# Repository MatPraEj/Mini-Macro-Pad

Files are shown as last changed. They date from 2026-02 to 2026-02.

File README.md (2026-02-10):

# Mini-Macro-Pad

Mini macropad is a 6 key "macropad" with a rotary encoder and OLED Display to allow for flexibility and the very important cool factor :D.

Why macropad in ""? Although it can function as a macropad when used with VIA, its main purpose is to act as a second mini keyboard with the RCTL, RSFT, LEFT, UP, DOWN, RIGHT buttons to serve as a sort of controller for PC where the second player plays on arrow keys and two buttons!

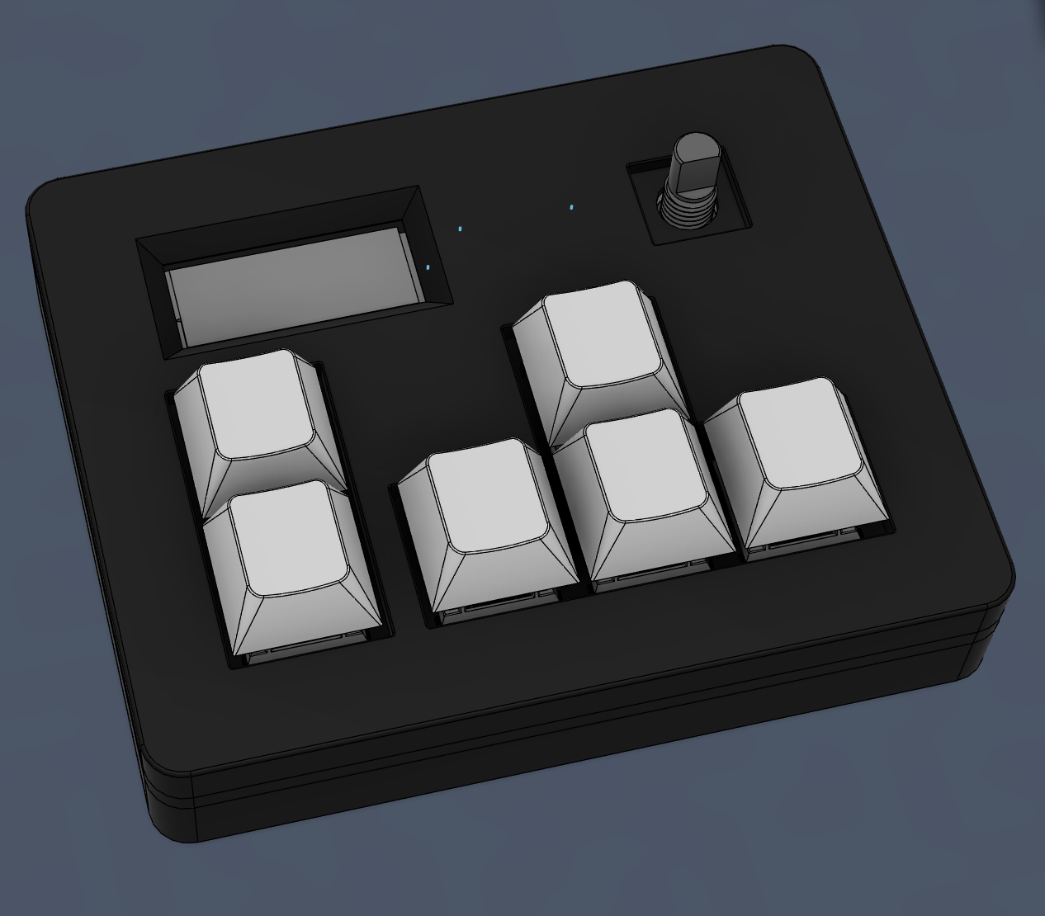
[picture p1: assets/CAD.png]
the whole macropad assembly


## Features:
- a Sturdy case with multiple points where the PCB is supported to minimize flex
- a recessed USB-C port
- an EC11 Rotary encoder for versatilty
- a 32x128 OLED display for cool factor
- 6 keys
- and [VIA](https://www.caniusevia.com/) support

## CAD Model
The Mini macropad is put together using 4 M3x16mm bolts and 4 heatset inserts, with another 1 M3x6 bolt holding the PCB (there are slots for 3 if it turns out 1 is unstable)

There are 3 seperate pieces of the case: the bottom where the PCB sits on a raised ledge around the edges as well as center supports; the middle part that acts as the plate for keyswitches, it is 3mm thick to allow for sturdiness but has a recess around the switch holes so they can clip in; and the top which covers the middle plate and sits flush with the bottom of the keycaps.

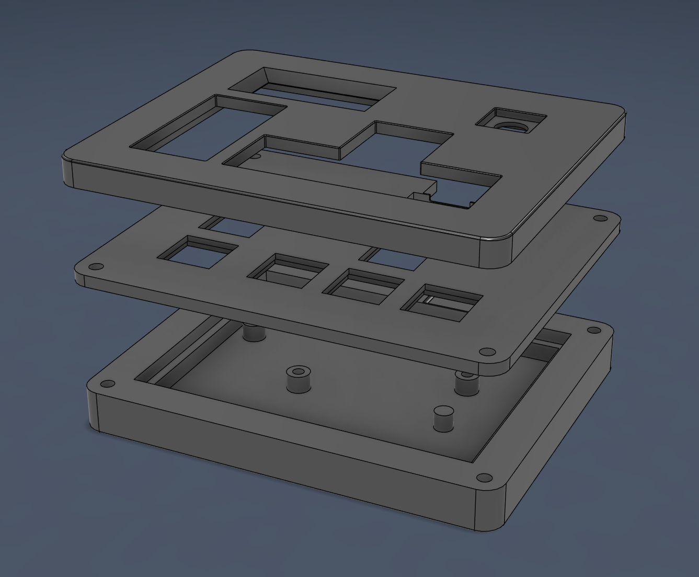
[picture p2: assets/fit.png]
how the case parts align


Learning Fusion 360 was a bit of a pain but I got the hang of it, now I can describe my experience only with one word: Nifty.

## PCB
Below is my PCB made in KiCad, Joe Scotto's guide's came in incredibly handy with this one.

I also snuck in a silkscreen easter egg of a sketch of the mini macropad :D

Schematic:

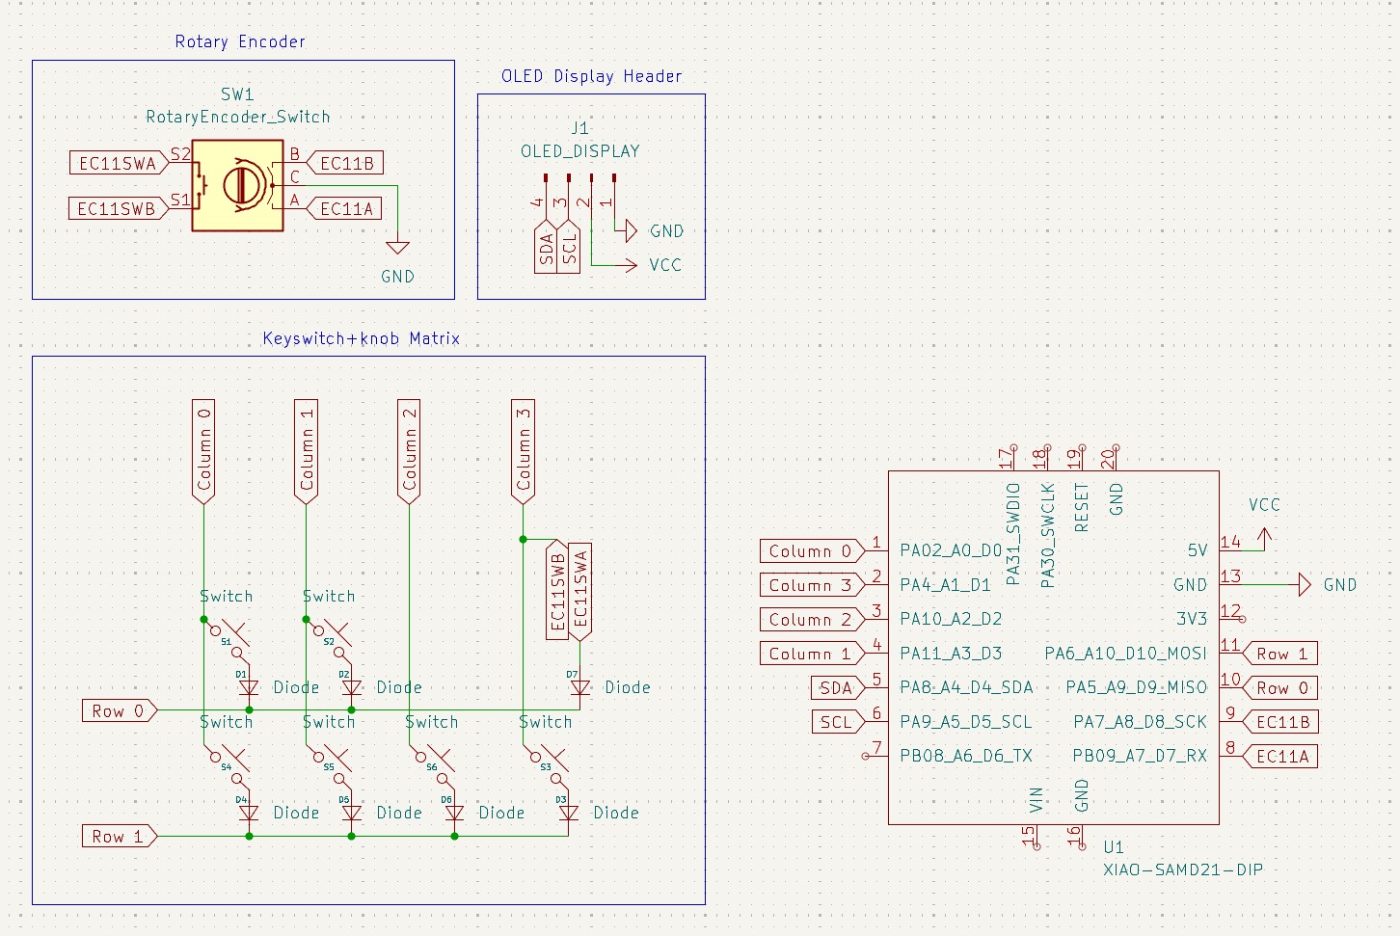
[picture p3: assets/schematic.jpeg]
the PCB schematic


PCB:

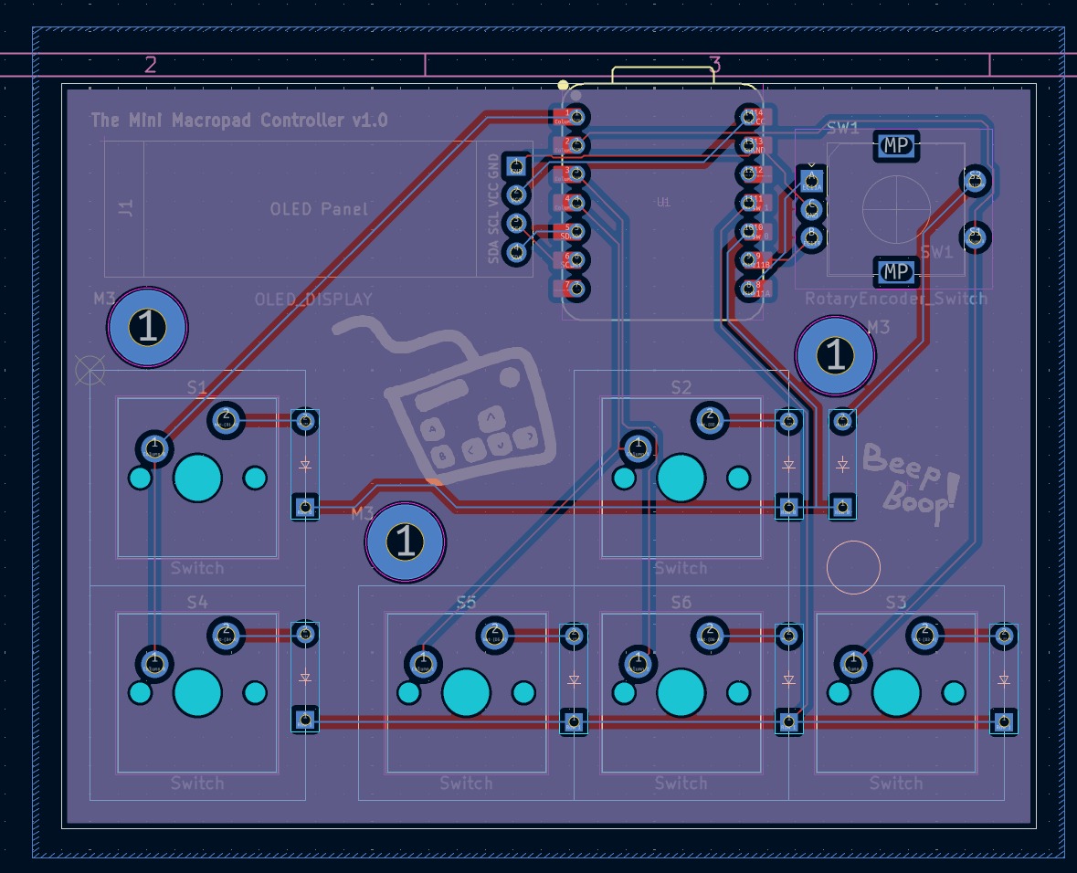
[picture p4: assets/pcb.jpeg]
the PCB


## Firmware
I used [QMK](https://qmk.fm/) for the firmware here, it was a massive pain to setup but if VIA works (fingers crossed!) it will be worth it, if it doesn't I'll do whatever to make it work.

By default:
- the rotary encoder changes volume and mutes/unmutes media when pressed
- the 6 keys act as a mini gamepad posing as UP, DOWN, LEFT, RIGHT and RCTL and RSFT
- the OLED screen displays an animation of a seal (by request of a friend)

VIA will allow me to change these keyboard mappings, allowing flexibility and allowing me to use it as an actual macropad :D

## BOM
Below is everything I'll need to build this:
- 6x Cherry MX Switches
- 6x DSA Keycaps
- 4x M3x5x4 Heatset inserts
- 4x M3x16 SHCS Bolts
- 1x M3x6 SHCS Bolt (I will source this myself)
- 7x DO-35 Diodes
- 1x 0.91" 128x32 OLED Display
- 1x EC11 Rotary Encoder
- 1x Seed Studio XIAO RP2040
- 2x 2.54mm 1x7 pin headers
- 1x 2.54mm 1x4 pin header
- 1x Case (3 3d printed parts)
- 1x Custom PCB

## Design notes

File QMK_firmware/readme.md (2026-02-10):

# mini_macropad

mini_macropad

*A short description of the keyboard/project*

* Keyboard Maintainer: [Matej Prazsky](https://github.com/MatPraEj)
* Hardware Supported: *The PCBs, controllers supported*
* Hardware Availability: *Links to where you can find this hardware*

Make example for this keyboard (after setting up your build environment):

    make mini_macropad:default

Flashing example for this keyboard:

    make mini_macropad:default:flash

See the [build environment setup](https://docs.qmk.fm/#/getting_started_build_tools) and the [make instructions](https://docs.qmk.fm/#/getting_started_make_guide) for more information. Brand new to QMK? Start with our [Complete Newbs Guide](https://docs.qmk.fm/#/newbs).

## Bootloader

Enter the bootloader in 3 ways:

* **Bootmagic reset**: Hold down the key at (0,0) in the matrix (usually the top left key or Escape) and plug in the keyboard
* **Physical reset button**: Briefly press the button on the back of the PCB - some may have pads you must short instead
* **Keycode in layout**: Press the key mapped to `QK_BOOT` if it is available

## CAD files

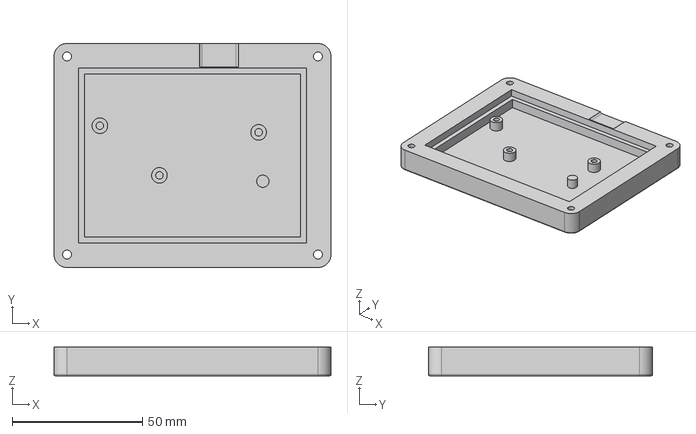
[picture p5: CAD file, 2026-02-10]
production/Bottom.step
106.4 x 86.0 x 11.0 mm

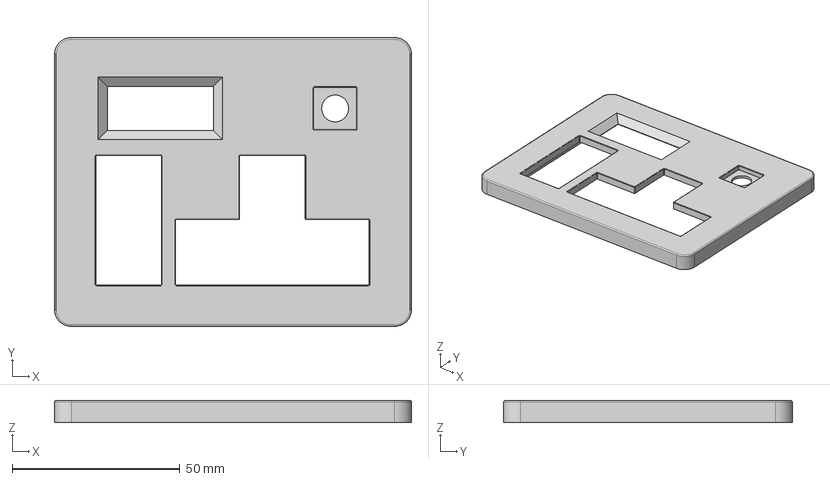
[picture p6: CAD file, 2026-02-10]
production/Top.step
106.4 x 86.0 x 6.60 mm

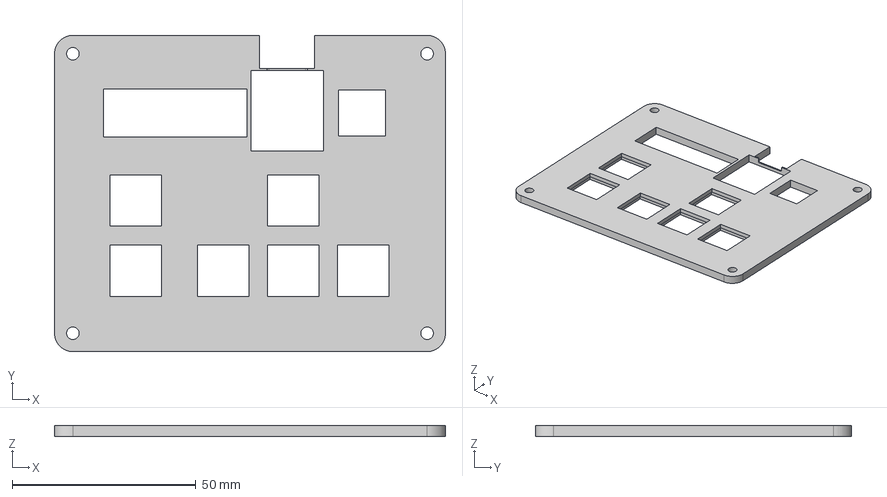
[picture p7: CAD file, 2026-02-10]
production/Middle.step
106.4 x 86.0 x 3.00 mm

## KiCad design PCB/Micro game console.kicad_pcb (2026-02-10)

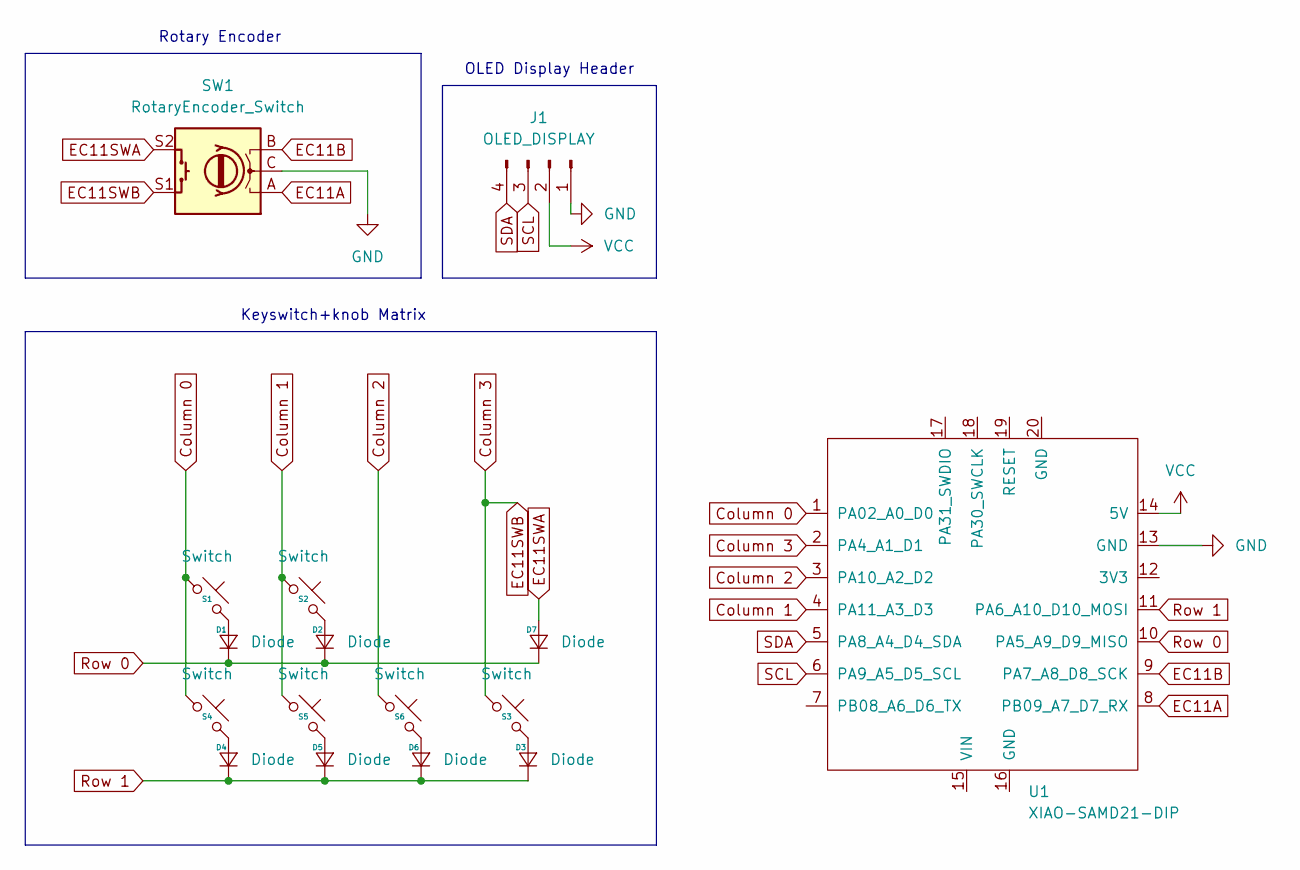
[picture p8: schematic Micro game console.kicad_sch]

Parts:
D1, D2, D3, D4, D5, D6, D7: Diode; Diode_DO-35
J1: OLED_DISPLAY; SSD1306-0.91-OLED-4pin-128x32
S1, S2, S3, S4, S5, S6: Switch; MX_PCB_1.00u
SW1: RotaryEncoder_Switch; RotaryEncoder_Alps_EC11E-Switch_Vertical_H20mm
U1: XIAO-SAMD21-DIP

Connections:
Column 0: S1.1, S4.1, U1.1 (PA02_A0_D0)
Column 1: S2.1, S5.1, U1.4 (PA11_A3_D3)
Column 2: S6.1, U1.3 (PA10_A2_D2)
Column 3: S3.1, SW1.S1, U1.2 (PA4_A1_D1)
EC11A: SW1.A, U1.8 (PB09_A7_D7_RX)
EC11B: SW1.B, U1.9 (PA7_A8_D8_SCK)
EC11SWA: D7.2 (A), SW1.S2
GND: J1.1, SW1.C, U1.13 (GND)
unnamed: D1.2 (A), S1.2
unnamed: D2.2 (A), S2.2
unnamed: D3.2 (A), S3.2
unnamed: D4.2 (A), S4.2
unnamed: D5.2 (A), S5.2
unnamed: D6.2 (A), S6.2
Row 0: D1.1 (K), D2.1 (K), D7.1 (K), U1.10 (PA5_A9_D9_MISO)
Row 1: D3.1 (K), D4.1 (K), D5.1 (K), D6.1 (K), U1.11 (PA6_A10_D10_MOSI)
SCL: J1.3, U1.6 (PA9_A5_D5_SCL)
SDA: J1.4, U1.5 (PA8_A4_D4_SDA)
VCC: J1.2, U1.14 (5V)

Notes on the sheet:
OLED Display Header
Rotary Encoder
Keyswitch+knob Matrix

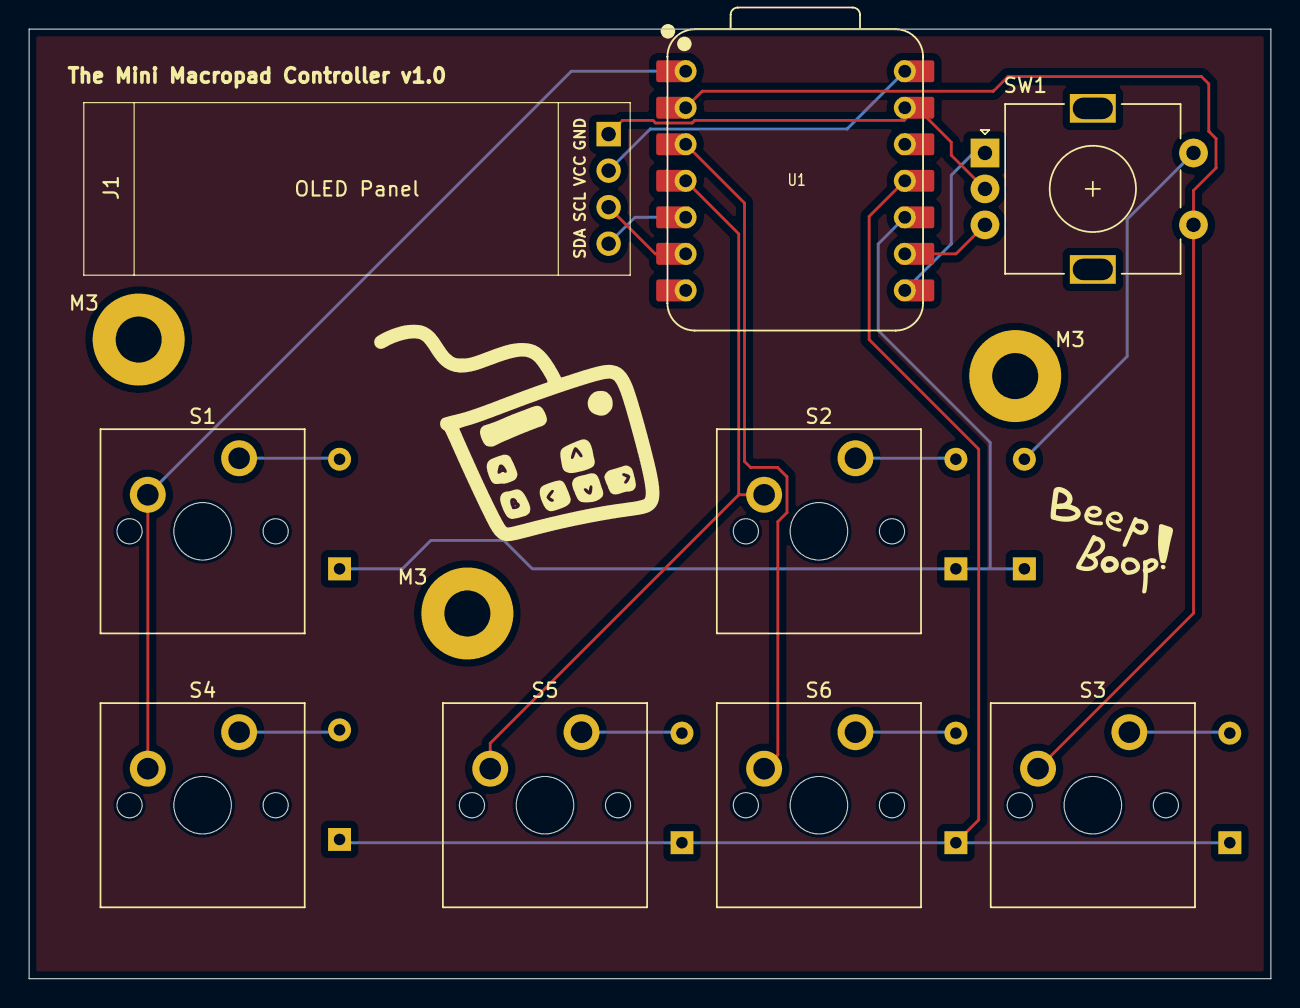
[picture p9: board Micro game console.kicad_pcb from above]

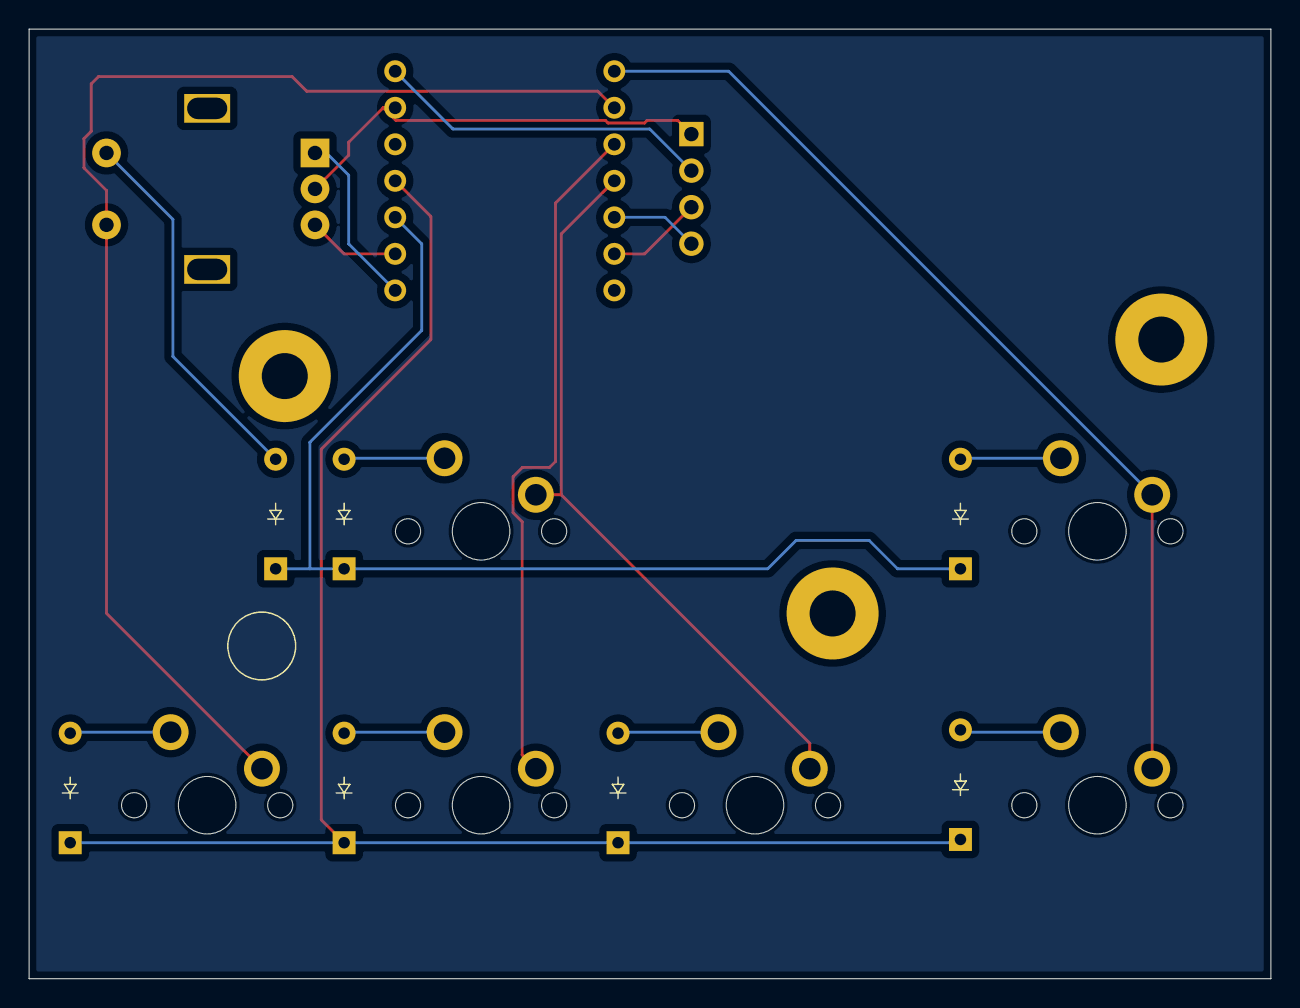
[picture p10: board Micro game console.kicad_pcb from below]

Board: 2 copper layers, 86.4 x 66.0 mm, 20 parts (7 on the bottom side), 19 nets.

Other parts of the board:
M3, M3#2, M3#3: MountingHole_3.2mm_M3_Pad
sdasd: LOGO; beep_boop

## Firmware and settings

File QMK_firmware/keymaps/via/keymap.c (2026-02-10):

// Copyright 2023 QMK
// SPDX-License-Identifier: GPL-2.0-or-later

#include QMK_KEYBOARD_H

const uint16_t PROGMEM keymaps[][MATRIX_ROWS][MATRIX_COLS] = {
    [0] = LAYOUT(
        KC_RSFT,   KC_UP,   KC_MUTE,
        KC_RCTL,   KC_LEFT,   KC_DOWN,   KC_RIGHT
    )
};

#if defined (ENCODER_MAP_ENABLE)
const uint16_t PROGMEM encoder_map[][NUM_ENCODERS][2] = {
    [0] = { ENCODER_CCW_CW(KC_VOLD, KC_VOLU) } //set functions of rotating encoder
}; 
#endif

#if defined (OLED_ENABLE)

// Animation parameters
#define FRAME_DURATION 333 // how long each frame is in ms

// Animation variables
uint32_t timer = 0;
uint8_t current_frame = 0;

// Render animation
static void render_animation(void) {

    // 'frame_0_delay-0', 128x32px
    static const char epd_bitmap_frame_0_delay_0 [] PROGMEM = {
        0x00, 0x00, 0x00, 0x00, 0x00, 0x00, 0x00, 0x00, 0x00, 0x00, 0x00, 0x00, 0x00, 0x00, 0x00, 0x00, 
        0x00, 0x00, 0x00, 0x00, 0xf0, 0x00, 0x00, 0x00, 0x00, 0x00, 0x00, 0x7f, 0xf8, 0x00, 0x00, 0x00, 
        0x00, 0x00, 0x00, 0x01, 0x98, 0x00, 0x00, 0x00, 0x00, 0x00, 0x07, 0xc0, 0x0e, 0x00, 0x00, 0x00, 
        0x00, 0x00, 0x00, 0x01, 0x0c, 0x00, 0x00, 0x00, 0x00, 0x00, 0x3c, 0x00, 0x01, 0x80, 0x00, 0x00, 
        0x00, 0x00, 0x00, 0x03, 0x04, 0x00, 0x00, 0x00, 0x00, 0x03, 0xe0, 0x00, 0x00, 0xc0, 0x00, 0x00, 
        0x00, 0x00, 0x00, 0x02, 0x06, 0x00, 0x00, 0x00, 0x00, 0x1e, 0x00, 0x00, 0x06, 0x20, 0x00, 0x00, 
        0x00, 0x00, 0x00, 0x02, 0x02, 0x00, 0x00, 0x00, 0x00, 0xf0, 0x00, 0x00, 0x04, 0x30, 0x00, 0x00, 
        0x00, 0x00, 0x00, 0x02, 0x02, 0x00, 0x00, 0x00, 0x03, 0x80, 0x00, 0x00, 0x00, 0x10, 0x00, 0x00, 
        0x00, 0x00, 0x00, 0x02, 0x02, 0x00, 0x00, 0x00, 0x0e, 0x00, 0x00, 0x00, 0x00, 0x08, 0x00, 0x00, 
        0x00, 0x00, 0x00, 0x02, 0x02, 0x00, 0x00, 0x00, 0x18, 0x00, 0x00, 0x00, 0x00, 0x04, 0x00, 0x00, 
        0x00, 0x00, 0x00, 0x01, 0x02, 0x00, 0x00, 0x00, 0x70, 0x00, 0x00, 0x00, 0x00, 0x84, 0x00, 0x00, 
        0x00, 0x00, 0x00, 0x01, 0x02, 0x00, 0x00, 0x01, 0xc0, 0x00, 0x00, 0x00, 0x00, 0x64, 0x00, 0x00, 
        0x00, 0x00, 0x03, 0xff, 0x82, 0x00, 0x00, 0x0f, 0x00, 0x00, 0x00, 0x00, 0x00, 0x18, 0x00, 0x00, 
        0x00, 0x00, 0x0e, 0x01, 0x87, 0x80, 0x00, 0x78, 0x00, 0x00, 0x00, 0x00, 0x00, 0xf0, 0x00, 0x00, 
        0x00, 0x00, 0x18, 0x00, 0xcc, 0xf0, 0x03, 0x80, 0x00, 0x00, 0x00, 0x00, 0x07, 0x80, 0x00, 0x00, 
        0x00, 0x00, 0x10, 0x00, 0x58, 0x0f, 0xfe, 0x00, 0x00, 0x00, 0x00, 0x00, 0x7c, 0x00, 0x00, 0x00, 
        0x00, 0x00, 0x18, 0x00, 0x70, 0x00, 0x00, 0x00, 0x00, 0x00, 0x00, 0x40, 0xc0, 0x00, 0x00, 0x00, 
        0x00, 0x00, 0x0e, 0x00, 0xc0, 0x00, 0x00, 0x00, 0x00, 0x00, 0x00, 0x41, 0x80, 0x00, 0x00, 0x00, 
        0x00, 0x00, 0x03, 0x81, 0x80, 0x00, 0x00, 0x00, 0x00, 0x00, 0x00, 0x23, 0x00, 0x00, 0x00, 0x00, 
        0x00, 0x00, 0x00, 0xff, 0x80, 0x00, 0x00, 0x00, 0x00, 0x00, 0x08, 0x1e, 0x00, 0x00, 0x00, 0x00, 
        0x00, 0x00, 0x00, 0x00, 0x80, 0x00, 0x00, 0x00, 0x00, 0x00, 0x08, 0x08, 0x00, 0x00, 0x00, 0x00, 
        0x00, 0x00, 0x00, 0x00, 0x40, 0x00, 0x00, 0x00, 0x00, 0x00, 0x04, 0x04, 0x00, 0x00, 0x00, 0x00, 
        0x00, 0x00, 0x00, 0x00, 0x20, 0x00, 0x00, 0x00, 0x00, 0x00, 0x04, 0x03, 0x00, 0x00, 0x00, 0x00, 
        0x00, 0x00, 0x00, 0x00, 0x30, 0x00, 0x00, 0x00, 0x00, 0x00, 0x02, 0x00, 0x80, 0x00, 0x00, 0x00, 
        0x00, 0x00, 0x00, 0x00, 0x18, 0x00, 0x00, 0x00, 0x00, 0x00, 0x06, 0x00, 0xc0, 0x00, 0x00, 0x00, 
        0x00, 0x00, 0x00, 0x00, 0x06, 0x00, 0x00, 0x00, 0x00, 0xff, 0xfd, 0x00, 0x30, 0x00, 0x00, 0x00, 
        0x00, 0x00, 0x00, 0x00, 0x03, 0x80, 0x00, 0x00, 0x1f, 0x80, 0x00, 0x80, 0x0c, 0x00, 0x00, 0x00, 
        0x00, 0x00, 0x00, 0x00, 0x00, 0xe0, 0x00, 0x00, 0x70, 0x00, 0x00, 0x40, 0x03, 0x00, 0x00, 0x00, 
        0x00, 0x00, 0x00, 0x00, 0x00, 0x3e, 0x00, 0x01, 0xc0, 0x00, 0x00, 0x20, 0x01, 0x00, 0x00, 0x00, 
        0x00, 0x00, 0x00, 0x00, 0x00, 0x01, 0xfc, 0x0f, 0x00, 0x00, 0x00, 0x18, 0x03, 0x00, 0x00, 0x00, 
        0x00, 0x00, 0x00, 0x00, 0x00, 0x00, 0x07, 0xf8, 0x00, 0x00, 0x00, 0x07, 0xfc, 0x00, 0x00, 0x00, 
        0x00, 0x00, 0x00, 0x00, 0x00, 0x00, 0x00, 0x00, 0x00, 0x00, 0x00, 0x00, 0x00, 0x00, 0x00, 0x00
    };
    // 'frame_1_delay-0', 128x32px
    static const char epd_bitmap_frame_1_delay_0 [] PROGMEM = {
        0x00, 0x00, 0x00, 0x00, 0x00, 0x00, 0x00, 0x00, 0x00, 0x00, 0x00, 0x00, 0x00, 0x00, 0x00, 0x00, 
        0x00, 0x00, 0x00, 0x00, 0x00, 0x00, 0x00, 0x00, 0x00, 0x00, 0x00, 0xff, 0x80, 0x00, 0x00, 0x00, 
        0x00, 0x00, 0x00, 0x00, 0x00, 0x00, 0x00, 0x00, 0x00, 0x00, 0x07, 0x80, 0xf0, 0x00, 0x00, 0x00, 
        0x00, 0x00, 0x00, 0x00, 0x00, 0x00, 0x00, 0x00, 0x00, 0x00, 0x38, 0x00, 0x1c, 0x00, 0x00, 0x00, 
        0x00, 0x00, 0x00, 0x1f, 0x80, 0x00, 0x00, 0x00, 0x00, 0x00, 0xe0, 0x00, 0x46, 0x00, 0x00, 0x00, 
        0x00, 0x00, 0x00, 0x30, 0xc0, 0x00, 0x00, 0x00, 0x00, 0x03, 0x80, 0x00, 0x62, 0x00, 0x00, 0x00, 
        0x00, 0x00, 0x00, 0x20, 0x60, 0x00, 0x00, 0x00, 0x00, 0x0e, 0x00, 0x00, 0x01, 0x00, 0x00, 0x00, 
        0x00, 0x00, 0x00, 0x30, 0x30, 0x00, 0x00, 0x00, 0x00, 0x38, 0x00, 0x00, 0x00, 0x80, 0x00, 0x00, 
        0x00, 0x00, 0x00, 0x10, 0x18, 0x00, 0x00, 0x00, 0x01, 0xe0, 0x00, 0x00, 0x00, 0x40, 0x00, 0x00, 
        0x00, 0x00, 0x00, 0x18, 0x08, 0x00, 0x00, 0x00, 0x7f, 0x00, 0x00, 0x00, 0x08, 0x40, 0x00, 0x00, 
        0x00, 0x00, 0x00, 0x0c, 0x08, 0x00, 0x00, 0x0f, 0xc0, 0x00, 0x00, 0x00, 0x04, 0xc0, 0x00, 0x00, 
        0x00, 0x00, 0x00, 0x06, 0x0c, 0x00, 0x00, 0x38, 0x00, 0x00, 0x00, 0x00, 0x0f, 0x80, 0x00, 0x00, 
        0x00, 0x00, 0x00, 0x03, 0x04, 0x00, 0x00, 0x60, 0x00, 0x00, 0x00, 0x00, 0x38, 0x00, 0x00, 0x00, 
        0x00, 0x00, 0x07, 0xfd, 0xc4, 0x00, 0x01, 0x80, 0x00, 0x00, 0x00, 0x00, 0x20, 0x00, 0x00, 0x00, 
        0x00, 0x00, 0x04, 0x07, 0xf6, 0x00, 0x03, 0x00, 0x00, 0x00, 0x00, 0x00, 0x40, 0x00, 0x00, 0x00, 
        0x00, 0x00, 0x04, 0x00, 0x63, 0x80, 0x02, 0x00, 0x00, 0x00, 0x00, 0x01, 0x80, 0x00, 0x00, 0x00, 
        0x00, 0x00, 0x06, 0x00, 0x40, 0xc0, 0x0c, 0x00, 0x00, 0x00, 0x00, 0x47, 0x00, 0x00, 0x00, 0x00, 
        0x00, 0x00, 0x03, 0x00, 0xc0, 0x60, 0x08, 0x00, 0x00, 0x00, 0x00, 0x5c, 0x00, 0x00, 0x00, 0x00, 
        0x00, 0x00, 0x01, 0x87, 0x80, 0x38, 0x38, 0x00, 0x00, 0x00, 0x00, 0x30, 0x00, 0x00, 0x00, 0x00, 
        0x00, 0x00, 0x00, 0xfc, 0x80, 0x0f, 0xe0, 0x00, 0x00, 0x00, 0x08, 0x18, 0x00, 0x00, 0x00, 0x00, 
        0x00, 0x00, 0x00, 0x00, 0xc0, 0x00, 0x00, 0x00, 0x00, 0x00, 0x08, 0x0c, 0x00, 0x00, 0x00, 0x00, 
        0x00, 0x00, 0x00, 0x00, 0x40, 0x00, 0x00, 0x00, 0x00, 0x00, 0x04, 0x06, 0x00, 0x00, 0x00, 0x00, 
        0x00, 0x00, 0x00, 0x00, 0x60, 0x00, 0x00, 0x00, 0x00, 0x00, 0x04, 0x02, 0x00, 0x00, 0x00, 0x00, 
        0x00, 0x00, 0x00, 0x00, 0x30, 0x00, 0x00, 0x00, 0x00, 0x00, 0x06, 0x01, 0x00, 0x00, 0x00, 0x00, 
        0x00, 0x00, 0x00, 0x00, 0x18, 0x00, 0x00, 0x01, 0xff, 0xf0, 0x39, 0x01, 0x00, 0x00, 0x00, 0x00, 
        0x00, 0x00, 0x00, 0x00, 0x0e, 0x00, 0x00, 0x0f, 0x00, 0x0f, 0xc0, 0x80, 0x80, 0x00, 0x00, 0x00,
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

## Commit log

2026-02-10 Added PCB files to the PCB folder
    [Micro game console.kicad_pcb, Micro game console.kicad_sch]
2026-02-10 Fix formatting for Schematic and PCB sections
